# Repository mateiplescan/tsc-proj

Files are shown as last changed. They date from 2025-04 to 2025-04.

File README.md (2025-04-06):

# OpenBook &copy; Matei-Bogdan Plescan 2025

## Diagrama bloc
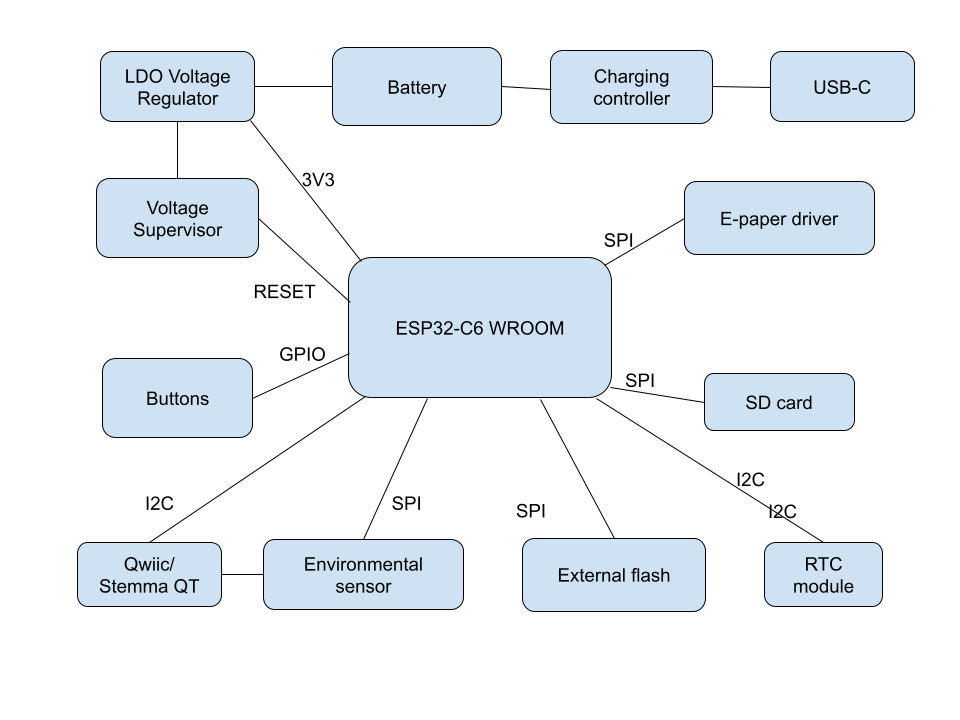
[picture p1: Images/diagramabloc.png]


## Randare 3D
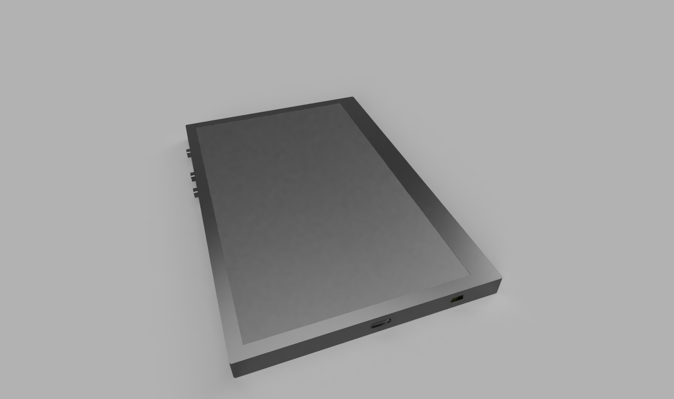
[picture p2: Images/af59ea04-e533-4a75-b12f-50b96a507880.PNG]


## Bill of Materials

| Piesă | Qty | Datasheet | Aprovizionare  |
|---|---|---|---|
| ADAFRUIT_CHIP-LED0603 | 1 | [Link](https://www.snapeda.com/parts/KP-1608SURCK/Kingbright/datasheet/) | [Link](https://www.arrow.com/en/products/kp-1608surck/kingbright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) |
| SJ | 1 | [Link](https://grabcad.com/library/solder-jumpers-1) | [Link](https://grabcad.com/library/solder-jumpers-1) |
| ESP32_WROVER_EAGLE-LTSPICE_R0402 | 24 | [Link](https://ro.mouser.com/ProductDetail/YAGEO/RC0402FR-07100KL?qs=mnq%2FyloZIXzTlUn7JAHSWg%3D%3D) | [Link](https://ro.mouser.com/ProductDetail/YAGEO/RC0402FR-07100KL?qs=mnq%2FyloZIXzTlUn7JAHSWg%3D%3D) |
| ESP32_WROVER_EAGLE-LTSPICE_C0402 | 26 | [Link](https://eu.mouser.com/datasheet/2/447/upy_gphc_x5r_4v_to_50v-3461255.pdf) | [Link](https://eu.mouser.com/ProductDetail/YAGEO/CC0402MRX5R5BB106?qs=zEY9bCHj09eCmUJdZuS5Lg%3D%3D) |
| RCL_CT3528 | 1 | [Link](https://ro.mouser.com/ProductDetail/KEMET/T491B107M006AT?qs=U312oeP%2FpiHOgyk6KO2m0g%3D%3D) | [Link](https://ro.mouser.com/ProductDetail/KEMET/T491B107M006AT?qs=U312oeP%2FpiHOgyk6KO2m0g%3D%3D) |
| 112ATAARR03ATTEND | 1 | [Link](https://store.comet.bg/download-file.php?id=27596) | [Link](https://store.comet.srl.ro/Catalogue/Product/43497/) |
| ESP32_WROVER_SPARKFUN-DISCRETESEMI_SOT23-3 | 2 | [Link](https://www.diodes.com/assets/Datasheets/DMG2305UX.pdf) | [Link](https://eu.mouser.com/ProductDetail/Diodes-Incorporated/DMG2305UX-7?qs=L1DZKBg7t5F%2FNBHrjfxC%252Bg%3D%3D) |
| IND_4828-WE-TPC_WRE | 1 | [Link](https://www.we-online.com/components/products/datasheet/744043680.pdf) | [Link](https://eu.mouser.com/ProductDetail/Wurth-Elektronik/744043680?qs=PGXP4M47uW6VkZq%252BkzjrHA%3D%3D) |
| SOT95P280X125-5N | 1 | [Link](https://fscdn.rohm.com/en/products/databook/datasheet/ic/power/voltage_detector/bd52xxg-e.pdf) | [Link](https://eu.mouser.com/ProductDetail/ROHM-Semiconductor/BD5229G-TR?qs=4kLU8WoGk0vvnhrrYwdszw%3D%3D) |
| MYBUTTON | 2 | [Link](https://www3.panasonic.biz/ac/e_download/control/switch/light-touch/catalog/sw_lt_eng_3529s_side.pdf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) | [Link](https://eu.mouser.com/ProductDetail/Panasonic/EVQ-P7L01P?qs=rJ%252BziJWpyszWhhNszc02jQ%3D%3D) |
| CAPCP3225X100N | 1 | [Link](https://eu.mouser.com/datasheet/2/360/Seiko_Instruments_MicroBattery_E_20230330_2024Jan_-3561061.pdf) | [Link](https://eu.mouser.com/ProductDetail/Seiko-Semiconductors/CPH3225A?qs=3etwrb1wR%252BhUOph6lAO7eg%3D%3D) |
| SOIC127P1032X265-16N | 1 | [Link](https://eu.mouser.com/datasheet/2/609/DS3231-3421123.pdf) | [Link](https://eu.mouser.com/ProductDetail/Analog-Devices-Maxim-Integrated/DS3231SN?qs=1eQvB6Dk1vhUlr8%2FOrV0Fw%3D%3D) |
| XCVR_ESP32-C6-WROOM-1-N8 | 1 | [Link](https://eu.mouser.com/datasheet/2/891/Espressif_ESP32_C6_WROOM_1__Datasheet_V0_1_PRELIMI-3239987.pdf) | [Link](https://eu.mouser.com/ProductDetail/Espressif-Systems/ESP32-C6-WROOM-1-N8?qs=8Wlm6%252BaMh8ST02Gmwp74cw%3D%3D) |
| ESP32C6_VARISTOR_CT/CN1812 | 1 | [Link](https://www.digikey.ro/en/products/detail/abracon-llc/AMCV-1812H-180-T/4245629) | [Link](https://www.digikey.ro/en/products/detail/abracon-llc/AMCV-1812H-180-T/4245629) |
| ESP32_WROVER_AVX---SD0805S020S1R0_AVX_SD0805S020S1R0_0 | 2 | [Link](https://eu.mouser.com/datasheet/2/40/schottky-3165252.pdf) | [Link](https://eu.mouser.com/ProductDetail/KYOCERA-AVX/SD0805S020S1R0?qs=jCA%252BPfw4LHbpkAoSnwrdjw%3D%3D) |
| ESP32_WROVER_BME680_PSON80P300X300X100-8N | 1 | [Link](https://www.bosch-sensortec.com/media/boschsensortec/downloads/datasheets/bst-bme680-ds001.pdf) | [Link](https://store.comet.srl.ro/Catalogue/Product/50164/) |
| ESP32_WROVER_SPARKFUN-IC-POWER_SOT23-5 | 1 | [Link](https://eu.mouser.com/datasheet/2/268/MCP73831_Family_Data_Sheet_DS20001984H-3441711.pdf) | [Link](https://eu.mouser.com/ProductDetail/Microchip-Technology/MCP73831T-4ADI-OT?qs=hH%252BOa0VZEiBTiqxSV9eepQ%3D%3D) |
| FH34SRJ24S05SH99 | 1 | [Link](https://eu.mouser.com/datasheet/2/760/xc6220-3371556.pdf) | [Link](https://eu.mouser.com/ProductDetail/Torex-Semiconductor/XC6220A331MR-G?qs=AsjdqWjXhJ8ZSWznL1J0gg%3D%3D) |
| SON50P200X200X80-9N | 1 | [Link](https://eu.mouser.com/datasheet/2/609/MAX17048_MAX17049-3469099.pdf) | [Link](https://eu.mouser.com/ProductDetail/Analog-Devices-Maxim-Integrated/MAX17048G%2bT10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) |
| SOD3716X135N | 3 | [Link](https://eu.mouser.com/datasheet/2/40/schottky-3165252.pdf) | [Link](https://eu.mouser.com/ProductDetail/KYOCERA-AVX/SD0805S020S1R0?qs=jCA%252BPfw4LHbpkAoSnwrdjw%3D%3D) |
| DIOC1608X36N | 6 | [Link](https://www.littelfuse.com/assetdocs/pulseguard-esd-suppressors-pgb1-datasheet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) | [Link](https://eu.mouser.com/ProductDetail/Littelfuse/PGB1010603MR?qs=gu7KAQ731URLg4GSnNNN7Q%3D%3D) |
| JST04_1MM_RA | 1 | [Link](https://eu.mouser.com/datasheet/2/813/Qwiic_Connector_Datasheet-1223982.pdf) | [Link](https://eu.mouser.com/ProductDetail/SparkFun/PRT-14417?qs=wd5RIQLrsJhgdz%2FpmZ%2F3GQ%3D%3D) |
| SAMACSYS_PARTS_USB4110GFA | 1 | [Link](https://eu.mouser.com/datasheet/2/837/GCT_USB4110_Product_Drawing___20k_cycles-3455479.pdf) | [Link](https://eu.mouser.com/ProductDetail/GCT/USB4110-GF-A?qs=KUoIvG%2F9IlYiZvIXQjyJeA%3D%3D) |
| SOT65P210X110-3N | 1 | [Link](https://www.vishay.com/doc?63399) | [Link](https://eu.mouser.com/ProductDetail/Vishay-Semiconductors/SI1308EDL-T1-GE3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) |
| SOT95P280X145-6N | 1 | [Link](https://eu.mouser.com/datasheet/2/389/usblc6_2sc6y-1852505.pdf) | [Link](https://eu.mouser.com/ProductDetail/STMicroelectronics/USBLC6-2SC6Y?qs=gNDSiZmRJS%2FOgDexvXkdow%3D%3D) |
| SON127P600X800X80-9N | 11 | [Link](https://eu.mouser.com/datasheet/2/949/Winbond_W25Q512JV_Datasheet-3240039.pdf) | [Link](https://eu.mouser.com/ProductDetail/Winbond/W25Q512JVEIQ?qs=l7cgNqFNU1jw6svr3at6tA%3D%3D) |
| SOT95P280X120-5N | 1 | [Link](https://eu.mouser.com/datasheet/2/760/xc6220-3371556.pdf) | [Link](https://eu.mouser.com/ProductDetail/Torex-Semiconductor/XC6220A331MR-G?qs=AsjdqWjXhJ8ZSWznL1J0gg%3D%3D) |

## Descriere Hardware

OpenBook este bazat pe microcontrollerul ESP32-C6. Dispozitivul integrează un display E-Paper, senzori de mediu, stocare de date pe card SD și memorie flash externă, un ceas de timp real (RTC), management avansat al alimentării cu baterie Li-Po și conector de expansiune Qwiic.

### 1. Microcontroller

* **Componentă:** Modul ESP32-C6-WROOM-1-N8 de la Espressif.
* **Procesor:** Nucleu RISC-V single-core pe 32 de biți, până la 160 MHz.
* **Conectivitate:**
    * Wi-Fi 6 (802.11ax)
    * Bluetooth 5 / Bluetooth Low Energy (BLE)
    * Thread/Zigbee (802.15.4)
* **Memorie:** Include SRAM intern și suportă memorie flash externă (utilizată în design).
* **Interfețe:** Dispune de multiple periferice hardware, inclusiv SPI, I2C, SDIO, USB Serial/JTAG, GPIO, ADC, etc., utilizate extensiv în acest design pentru a comunica cu celelalte componente.
* **Rol:** Acționează ca unitate centrală de procesare, controlând toate celelalte module, colectând date de la senzori, gestionând afișajul, stocarea datelor și comunicațiile wireless.

### 2. Managementul Alimentării

* **Intrare Principală:** Conector USB Type-C.
    * Furnizează 5V (VBUS) pentru alimentarea sistemului și încărcarea bateriei.
    * Include circuite de protecție ESD (USBLC6-2SCISY).
* **Încărcare Baterie:**
    * **Componentă:** MCP73831T-2ACI/OT (Li-Po Battery Charging Controller).
    * **Funcționalitate:** Gestionează procesul de încărcare pentru o baterie de la sursa de 5V (USB).
    * **Indicator Status:** Pinul STAT (conectat la ESP32-C6) indică starea procesului de încărcare. Un LED (CHG_LED) oferă indicație vizuală.
* **Baterie:** Conector standard pentru baterie Li-Po.
* **Regulator de Tensiune:**
    * **Componentă:** XC8220A331MR-G (LDO Voltage Regulator).
    * **Funcționalitate:** Primește tensiune fie de la VBUS (USB 5V), fie de la bateria Li-Po (VBAT, ~3.0V-4.2V) și furnizează o tensiune stabilă de **3.3V** pentru alimentarea ESP32-C6 și a majorității perifericelor.
* **Monitorizare Baterie:**
    * **Componentă:** MAX17048G+T10.
    * **Funcționalitate:** Măsoară tensiunea bateriei și estimează starea de încărcare (SoC) și alte informații relevante despre baterie.
    * **Interfață:** Comunică cu ESP32-C6 prin **I2C**.
* **Supervizor Tensiune și Reset:**
    * **Componentă:** BD5229G-TR (Voltage Supervisor).
    * **Funcționalitate:** Monitorizează tensiunea de 3.3V. Dacă tensiunea scade sub un prag prestabilit, generează un semnal de RESET activ-low pe pinul EN al ESP32-C6, asigurând o pornire și funcționare stabilă. Permite și reset manual prin butonul RESET.

### 3. Afișaj (Display)

* **Tip:** E-Paper Display (EPD).
* **Conector:** FH34SR-245-0.5SH_99 (conector FPC cu 24 pini, pas 0.5mm).
* **Circuit Driver:** Include componente discrete (tranzistori MOSFET precum DMG2305UX-7, drivere de poartă precum 5123-11-GE3) necesare pentru a genera tensiunile și semnalele specifice EPD-urilor.
* **Interfață:** Circuitul driver este controlat de ESP32-C6 prin **SPI**.

### 4. Stocare Date

* **Card SD:**
    * **Slot:** Conector standard pentru card microSD.
    * **Interfață:** Conectat la ESP32-C6 folosind interfața **SPI**. Permite stocarea unor volume mari de date (ex: log-uri, fișiere de configurare, imagini).
* **Memorie Flash Externă:**
    * **Componentă:** W25Q512JVEIQ (NOR Flash, 64 Mbit).
    * **Interfață:** Conectată la ESP32-C6 prin **SPI**.
    * **Rol:** Utilizată pentru stocarea firmware-ului principal, a sistemului de fișiere, a configurațiilor sau a datelor critice.

### 5. Senzori și Timp Real

* **Senzor Ambiental:**
    * **Componentă:** BME688 de la Bosch Sensortec.
    * **Funcționalitate:** Măsoară temperatura, umiditatea relativă, presiunea barometrică și compuși organici volatili (VOC), oferind un indice al calității aerului (IAQ).
    * **Interfață:** Comunică cu ESP32-C6 prin **SPI**.
* **Ceas Timp Real (RTC):**
    * **Componentă:** DS3231SN.
    * **Funcționalitate:** Menține data și ora exactă independent de starea de alimentare a ESP32-C6, datorită unei surse de backup (Supercapacitor CPH3225A - C10). Esențial pentru timestamp-uri precise în log-uri.
    * **Interfață:** Comunică cu ESP32-C6 prin **I2C**.

### 6. Interfață Utilizator și Expansiune

* **Butoane:**
    * **RESET:** Buton tactil conectat la intrarea supervizorului de tensiune (și implicit la pinul EN al ESP32-C6) pentru reset manual.
    * **BOOT (IO9):** Buton tactil conectat la GPIO9. Folosit în mod uzual pentru a pune ESP32 în modul bootloader (pentru programare firmware). Poate fi folosit și ca buton de uz general în aplicație.
    * **CHANGE (IO15):** Buton tactil conectat la GPIO15. Destinat utilizării generale în aplicație (ex: schimbare mod afișaj, trigger acțiune).
* **Conector Expansiune:**
    * **Tip:** Conector Qwiic / Stemma QT (standard SparkFun / Adafruit).
    * **Funcționalitate:** Expune magistrala **I2C** a ESP32-C6 (SDA, SCL), împreună cu 3.3V și GND, permițând conectarea ușoară a numeroase module și senzori externi compatibili.

### 7. Alocarea Pinilor ESP32-C6 (Modul U2)

| **Pin** | **Semnal** | **Componentă** | **Rol** |
|---|---|---|---|
| EN | RESET | Buton Reset | Intrare pentru resetarea sistemului |
| IO0 | INT_RTC | RTC DS3231SN | Întrerupere de la RTC pentru evenimente temporale |
| IO1 | 32KHZ | RTC DS3231SN | Semnal de ceas 32kHz de la modulul RTC |
| IO2 | MISO | Magistrala SPI | Intrare de date de la periferice SPI |
| IO3 | EPD_BUSY | Afișaj E-Paper | Monitorizarea stării de disponibilitate a afișajului |
| IO4 | SS_SD | Card SD | Selectare chip pentru cardul SD |
| IO5 | EPD_DC | Afișaj E-Paper | Selectare date/comandă pentru afișaj |
| IO6 | SCK | Magistrala SPI | Semnal de ceas pentru comunicația SPI |
| IO7 | MOSI | Magistrala SPI | Ieșire de date către periferice SPI |
| IO8 | GPIO8 | Uz general | Funcții auxiliare |
| IO9 | IO/BOOT | Buton Boot | Selectare mod boot/programare |
| IO10 | EPD_CS | Afișaj E-Paper | Selectare chip pentru afișajul E-Paper |
| IO11 | FLASH_CS | Flash NOR extern | Selectare chip pentru memoria flash |
| IO12 | USB_D- | Interfață USB  | Linie de date USB negativă |
| IO13 | USB_D+ | Interfață USB  | Linie de date USB pozitivă |
| IO15 | IO/CHANGE | Buton Change | Detectare schimbare de stare |
| IO16/TXD0 | TX | Debug Serial | Transmitere UART |
| IO17/RXD0 | RX | Debug Serial | Recepție UART |
| IO18 | RTC_RST | RTC DS3231SN | Control reset pentru RTC |
| IO19 | I2C_PW | Magistrala I2C | Control alimentare pentru dispozitivele I2C |
| IO20 | EPD_3V3_C | Afișaj E-Paper | Control alimentare pentru afișaj |
| IO21 | SDA | Magistrala I2C | Linie de date I2C |
| IO22 | SCL | Magistrala I2C | Linie de ceas I2C |
| IO23 | EPD_RST | Afișaj E-Paper | Control reset pentru afișaj |

### Justificarea utilizării pinilor ESP32-C6 în DeskAssistant v19:

Alocarea pinilor ESP32-C6 în acest design a fost făcută cu atenție pentru a optimiza funcționalitatea și a gestiona eficient resursele limitate ale microcontrolerului:

- **Grupare funcțională**: Pinii sunt organizați pentru a grupa funcționalitățile similare. De exemplu, pinii pentru interfața SPI (MISO, MOSI, SCK) sunt plasați strategic pentru a facilita rutarea PCB și a reduce interferențele.

- **Pini speciali pentru interfețe standard**: IO21 și IO22 sunt utilizați pentru SDA și SCL, fiind pinii standard recomandați pentru I2C pe ESP32. Similar, IO16 și IO17 sunt utilizați pentru funcțiile UART datorită implementării hardware dedicate.

- **Pini GPIO cu funcționalități speciale pentru afișajul E-Paper**: Afișajul E-Paper necesită control complex, de aceea are alocați mai mulți pini (EPD_BUSY, EPD_DC, EPD_CS, EPD_RST, EPD_3V3_C) pentru funcționarea corectă și eficientă.

- **Management energie**: Pinul IO19 este dedicat controlului alimentării dispozitivelor I2C, permițând economisirea energiei prin oprirea acestora când nu sunt utilizate, esențial pentru un dispozitiv alimentat de baterie.

- **Comunicație cu memoria externă**: Memoria flash NOR necesită acces rapid și fiabil, de aceea utilizează un pin dedicat pentru selecție (IO11) pe lângă liniile standard SPI.

- **Conectivitate USB**: Pinii IO12 și IO13 sunt utilizați pentru USB_D- și USB_D+, permițând conectivitatea directă prin USB fără circuite externe suplimentare.

- **Integrare RTC**: Modulul RTC are multiple conexiuni (INT_RTC, 32KHZ, RTC_RST) pentru o funcționalitate completă, oferind atât ceas precis, cât și capacitatea de a trezi microcontrolerul din starea de somn profund.

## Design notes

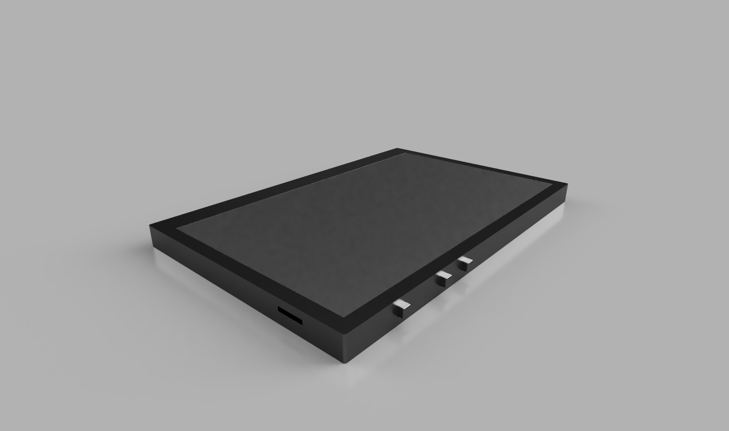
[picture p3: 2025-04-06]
Images/Full_product_2025-Apr-06_02-40-02PM-000_CustomizedView3090269307.png

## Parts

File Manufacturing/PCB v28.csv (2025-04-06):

Qty | Value | Device | Package | Parts | Description | ARROW_PART_NUMBER | ARROW_PRICE-STOCK | AVAILABILITY | CENTROID_NOT_SPECIFIED | CHECK_PRICES | COPYRIGHT | DATASHEET | DESCRIPTION | DIGIKEY_DESCRIPTION | DIGIKEY_PART_NUMBER | HEIGHT | LEAD_FREE | MANUFACTURER_NAME | MANUFACTURER_PART_NUMBER | MF | MFR_NAME | MOUSER_PART_NUMBER | MOUSER_PRICE-STOCK | MOUSER_TESTING_PART_NUMBER | MOUSER_TESTING_PRICE-STOCK | MP | MPN | PACKAGE | POPULARITY | PREFIX | PRICE | PROD_ID | PURCHASE-URL | ROHS | SNAPEDA_LINK | SPICEMODEL | SPICEPREFIX | TEMPERATURE_RANGE_HIGH | TEMPERATURE_RANGE_LOW | TP_SIGNAL_NAME | VALUE
1 |  | ADAFRUIT_LEDCHIP-LED0603 | ADAFRUIT_CHIP-LED0603 | CHG_LED | LED
1 |  | SJ | SJ | SJ1 | SMD solder JUMPER |  |  |  |  |  |  |  |  |  |  |  |  |  |  |  |  |  |  |  |  |  |  |  | 3
1 | 0.47 | ESP32_WROVER_EAGLE-LTSPICE_RR0402 | ESP32_WROVER_EAGLE-LTSPICE_R0402 | R3 | RESISTOR, European symbol |  |  |  |  |  |  |  |  |  |  |  |  |  |  |  |  |  |  |  |  |  |  |  |  |  |  |  |  |  |  | NONE | R
1 | 100k | ESP32_WROVER_EAGLE-LTSPICE_RR0402 | ESP32_WROVER_EAGLE-LTSPICE_R0402 | R1-PWRUSB | RESISTOR, European symbol |  |  |  |  |  |  |  |  |  |  |  |  |  |  |  |  |  |  |  |  |  |  |  |  |  |  |  |  |  |  | NONE | R
7 | 100nF | EAGLE-LTSPICE_CC0402 | EAGLE-LTSPICE_C0402 | C1, C2, C6, C8, C9, C10, C_DELAY | CAPACITOR, European symbol |  |  |  |  |  |  |  |  |  |  |  |  |  |  |  |  |  |  |  |  |  |  |  |  |  |  |  |  |  |  | NONE | C
1 | 100nF | ESP32_WROVER_EAGLE-LTSPICE_CC0402 | ESP32_WROVER_EAGLE-LTSPICE_C0402 | C4-USB | CAPACITOR, European symbol |  |  |  |  |  |  |  |  |  |  |  |  |  |  |  |  |  |  |  |  |  |  |  |  |  |  |  |  |  |  | NONE | C
1 | 100uF TANT | RCL_CPOL-EUCT3528 | RCL_CT3528 | C3 | POLARIZED CAPACITOR, European symbol |  |  |  |  |  |  |  |  |  |  |  |  |  |  |  |  |  |  |  |  |  |  |  | 0 |  |  |  |  |  |  |  | C
16 | 10k | ESP32_WROVER_EAGLE-LTSPICE_RR0402 | ESP32_WROVER_EAGLE-LTSPICE_R0402 | R1, R1_PINH, R1_PINH1, R2_PINH, R2_PINH1, R4, R5, R6, R7, R8, R9, R10, R_BOOT, R_CHANGE, R_CL1, R_RESET | RESISTOR, European symbol |  |  |  |  |  |  |  |  |  |  |  |  |  |  |  |  |  |  |  |  |  |  |  |  |  |  |  |  |  |  | NONE | R
1 | 10uF | EAGLE-LTSPICE_CC0402 | EAGLE-LTSPICE_C0402 | C7 | CAPACITOR, European symbol |  |  |  |  |  |  |  |  |  |  |  |  |  |  |  |  |  |  |  |  |  |  |  |  |  |  |  |  |  |  | NONE | C
1 | 112A-TAAR-R03_ATTEND | 112A-TAAR-R03_ATTEND | 112ATAARR03ATTEND | J4 | Micro SD Card Socket, Push-Push Type, Top Mount, SMT, H=1.83mm, 10u |  |  |  |  |  |  |  | Micro SD Card Socket | Push-Push Type | Top Mount | SMT | H=1.83mm | 10u |  |  | 1.9mm |  | ATTEND | 112A-TAAR-R03 ATTEND
1 | 15 | ESP32_WROVER_EAGLE-LTSPICE_RR0402 | ESP32_WROVER_EAGLE-LTSPICE_R0402 | R_CAPACITOR | RESISTOR, European symbol |  |  |  |  |  |  |  |  |  |  |  |  |  |  |  |  |  |  |  |  |  |  |  |  |  |  |  |  |  |  | NONE | R
1 | 1uF | EAGLE-LTSPICE_CC0402 | EAGLE-LTSPICE_C0402 | C5 | CAPACITOR, European symbol |  |  |  |  |  |  |  |  |  |  |  |  |  |  |  |  |  |  |  |  |  |  |  |  |  |  |  |  |  |  | NONE | C
10 | 1uF/50V | EAGLE-LTSPICE_CC0402 | EAGLE-LTSPICE_C0402 | EPD_C1, EPD_C2, EPD_C5, EPD_C6, EPD_C7, EPD_C8, EPD_C9, EPD_C10, EPD_C11, EPD_C12 | CAPACITOR, European symbol |  |  |  |  |  |  |  |  |  |  |  |  |  |  |  |  |  |  |  |  |  |  |  |  |  |  |  |  |  |  | NONE | C
1 | 2.2 | ESP32_WROVER_EAGLE-LTSPICE_RR0402 | ESP32_WROVER_EAGLE-LTSPICE_R0402 | R2 | RESISTOR, European symbol |  |  |  |  |  |  |  |  |  |  |  |  |  |  |  |  |  |  |  |  |  |  |  |  |  |  |  |  |  |  | NONE | R
1 | 200 | ESP32_WROVER_EAGLE-LTSPICE_RR0402 | ESP32_WROVER_EAGLE-LTSPICE_R0402 | R1_BAT | RESISTOR, European symbol |  |  |  |  |  |  |  |  |  |  |  |  |  |  |  |  |  |  |  |  |  |  |  |  |  |  |  |  |  |  | NONE | R
2 | 20V/4.2A/52mΩ/1.4W | ESP32_WROVER_SPARKFUN-DISCRETESEMI_MOSFET_PCH-DMG2305UX-7 | ESP32_WROVER_SPARKFUN-DISCRETESEMI_SOT23-3 | Q1, Q2 | P-channel MOSFETs |  |  |  |  |  |  |  |  |  |  |  |  |  |  |  |  |  |  |  |  |  |  |  |  |  |  | TRAN-14388 |  |  |  |  |  |  |  |  | 20V/4.2A/52mΩ/1.4W
1 | 2k | ESP32_WROVER_EAGLE-LTSPICE_RR0402 | ESP32_WROVER_EAGLE-LTSPICE_R0402 | R2_BAT | RESISTOR, European symbol |  |  |  |  |  |  |  |  |  |  |  |  |  |  |  |  |  |  |  |  |  |  |  |  |  |  |  |  |  |  | NONE | R
2 | 4.7uF | EAGLE-LTSPICE_CC0402 | EAGLE-LTSPICE_C0402 | C1_BAT, C2_BAT | CAPACITOR, European symbol |  |  |  |  |  |  |  |  |  |  |  |  |  |  |  |  |  |  |  |  |  |  |  |  |  |  |  |  |  |  | NONE | C
3 | 4.7uF | ESP32_WROVER_EAGLE-LTSPICE_CC0402 | ESP32_WROVER_EAGLE-LTSPICE_C0402 | C1_BAT1, C1_BAT2, C5-USB | CAPACITOR, European symbol |  |  |  |  |  |  |  |  |  |  |  |  |  |  |  |  |  |  |  |  |  |  |  |  |  |  |  |  |  |  | NONE | C
1 | 4.7uF/25V | EAGLE-LTSPICE_CC0402 | EAGLE-LTSPICE_C0402 | C4 | CAPACITOR, European symbol |  |  |  |  |  |  |  |  |  |  |  |  |  |  |  |  |  |  |  |  |  |  |  |  |  |  |  |  |  |  | NONE | C
2 | 5k1 | ESP32_WROVER_EAGLE-LTSPICE_RR0402 | ESP32_WROVER_EAGLE-LTSPICE_R0402 | R2-USB, R2-USB1 | RESISTOR, European symbol |  |  |  |  |  |  |  |  |  |  |  |  |  |  |  |  |  |  |  |  |  |  |  |  |  |  |  |  |  |  | NONE | R
1 | 68uH | 744043680IND_4828-WE-TPC_WRE | IND_4828-WE-TPC_WRE | L1 |  |  |  |  |  |  | Copyright (C) 2024 Ultra Librarian. All rights reserved. |  |  |  |  |  |  |  | 744043680 |  | Wurth Electronics
1 | BD5229G-TR | BD5229G-TR | SOT95P280X125-5N | IC1 | Voltage Detector with Adjustable Delay Time: CMOS processes are utilized to develop high precision, low current consumption CMOS reset ICs that allow arbitrary setting of the delay time. The extensive lineup includes both Nch Open Drain and CMOS output types in a wide range of detection voltages (from 2.3V to 6.0V, in 0.1V steps), enabling selection of the ideal solution based on customer requirements. In addition, the entire series is of course both lead-free and RoHS-compliant. |  |  |  |  |  |  |  | Voltage Detector with Adjustable Delay Time: CMOS processes are utilized to develop high precision | low current consumption CMOS reset ICs that allow arbitrary setting of the delay time. The extensive lineup includes both Nch Open Drain and CMOS output types in a wide range of detection voltages (from 2.3V to 6.0V | in 0.1V steps) | enabling selection of the ideal solution based on customer requirements. In addition | the entire series is of course both lead-free and RoHS-compliant. |  |  | 1.25mm |  | ROHM Semiconductor | BD5229G-TR |  |  | 755-BD5229G-TR | https://www.mouser.co.uk/ProductDetail/ROHM-Semiconductor/BD5229G-TR?qs=4kLU8WoGk0vvnhrrYwdszw%3D%3D
3 | BUTTON_CUSYOMV1 | BUTTON_CUSYOMV1 | MYBUTTON | BOOT_BUTTON, CHANGE_BUTTON, RESET_BUTTON
1 | CPH3225A | CPH3225A | CAPCP3225X100N | C10_SUPERCAP | Cap 0.011F 3.3V 1210 Flat Check availability |  |  | Not in stock |  | https://www.snapeda.com/parts/CPH3225A/Seiko+Instruments/view-part/?ref=eda |  |  | 11 mF (EDLC) Supercapacitor 3.3 V 1210 (3225 Metric) - - |  |  |  |  |  |  | Seiko Instruments |  |  |  |  |  | CPH3225A |  | 1210 Seiko |  |  | None |  | https://www.snapeda.com/api/url_track_click_mouser/?unipart_id=562593&manufacturer=Seiko Instruments&part_name=CPH3225A&search_term=None |  | https://www.snapeda.com/parts/CPH3225A/Seiko+Instruments/view-part/?ref=snap
1 | DS3231SN# | DS3231SN# | SOIC127P1032X265-16N | U3 | Real Time Clock Serial 16-Pin SOIC W T/R Check availability |  |  | In Stock |  | https://www.snapeda.com/parts/DS3231SN%23/Analog+Devices/view-part/?ref=eda |  |  | Extremely Accurate I²C-Integrated RTC/TCXO/Crystal |  |  |  |  |  |  | Analog Devices |  |  |  |  |  | DS3231SN# |  | SOIC-16 Maxim |  |  | None |  | https://www.snapeda.com/api/url_track_click_mouser/?unipart_id=99048&manufacturer=Analog Devices&part_name=DS3231SN#&search_term=None |  | https://www.snapeda.com/parts/DS3231SN%23/Analog+Devices/view-part/?ref=snap
1 | ESP32-C6-WROOM-1-N8 | ESP32-C6-WROOM-1-N8 | XCVR_ESP32-C6-WROOM-1-N8 | U2 | Check availability |  |  | In Stock |  | https://www.snapeda.com/parts/ESP32-C6-WROOM-1-N8/Espressif+Systems/view-part/?ref=eda |  |  | Multiprotocol Modules ESP32-C6 module | Wi-Fi 6 in 2.4 GHz band | Bluetooth 5 | Zigbee 3.0 and Thread. ESP34-WROOM Compatible - ENGINEERING SAMPLE |  |  |  |  |  |  | Espressif Systems |  |  |  |  |  | ESP32-C6-WROOM-1-N8 |  | None |  |  | None |  |  |  | https://www.snapeda.com/parts/ESP32-C6-WROOM-1-N8/Espressif+Systems/view-part/?ref=snap
1 | ESP32C6_VARISTORCN1812 | ESP32C6_VARISTORCN1812 | ESP32C6_VARISTOR_CT/CN1812 | PFMF.050.1 | VARISTOR |  |  |  |  |  |  |  |  |  |  |  |  |  |  |  |  |  |  |  |  |  |  |  | 0
2 | ESP32_WROVER_AVX---SD0805S020S1R0_AVX_SD0805S020S1R0_0_0AVX_SD0805S020S1R0_0_0 | ESP32_WROVER_AVX---SD0805S020S1R0_AVX_SD0805S020S1R0_0_0AVX_SD0805S020S1R0_0_0 | ESP32_WROVER_AVX---SD0805S020S1R0_AVX_SD0805S020S1R0_0 | D2, D7 | Schottky Barrier Rectifier Diode |  |  |  | No |  |  | http://datasheets.avx.com/schottky.pdf |  | DIODE SCHOTTKY 20V 1A 0805 | 478-7800-1-ND |  | yes |  |  | AVX |  | 581-SD0805S020S1R0 |  |  |  |  |  | 0805 (2012 metric) |  | D |  |  |  | yes |  |  |  | +125°C | -55°C
1 | ESP32_WROVER_BME680_BME680 | ESP32_WROVER_BME680_BME680 | ESP32_WROVER_BME680_PSON80P300X300X100-8N | SENSOR2 | Integrated Environmental Unit |  |  | Unavailable |  |  |  |  | Integrated Environmental Unit |  |  |  |  |  |  | Bosch Sensortec |  |  |  |  |  | BME680 |  | LGA-8 Bosch Tools |  |  | None
1 | ESP32_WROVER_SPARKFUN-IC-POWER_MCP73831 | ESP32_WROVER_SPARKFUN-IC-POWER_MCP73831 | ESP32_WROVER_SPARKFUN-IC-POWER_SOT23-5 | MCP73831 | MCP73831T Li-Ion, Li-Pol Controller |  |  |  |  |  |  |  |  |  |  |  |  |  |  |  |  |  |  |  |  |  |  |  |  |  |  | IC-09995
1 | FH34SRJ-24S-0.5SH_99_ | FH34SRJ-24S-0.5SH_99_ | FH34SRJ24S05SH99 | J1 | (0.50mm) Surface Mount, Right Angle |  |  |  |  |  |  |  | 24 Position FFC | FPC Connector Contacts | (0.50mm) Surface Mount | Right Angle |  |  | 1.1mm |  | Hirose | FH34SRJ-24S-0.5SH(99) |  |  | 798-FH34SRJ24S05SH99 | https://www.mouser.co.uk/ProductDetail/Hirose-Connector/FH34SRJ-24S-0.5SH99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
1 | MAX17048G+T10 | MAX17048G+T10 | SON50P200X200X80-9N | U4 | Check availability |  |  | In Stock |  | https://www.snapeda.com/parts/MAX17048G+T10/Analog+Devices/view-part/?ref=eda |  |  | 3µA 1-Cell/2-Cell Fuel Gauge with ModelGauge |  |  |  |  |  |  | Analog Devices |  |  |  |  |  | MAX17048G+T10 |  | TDFN-8 Maxim |  |  | None |  | https://www.snapeda.com/api/url_track_click_mouser/?unipart_id=329239&manufacturer=Analog Devices&part_name=MAX17048G+T10&search_term=None |  | https://www.snapeda.com/parts/MAX17048G+T10/Analog+Devices/view-part/?ref=snap
3 | MBR0530 | MBR0530 | SOD3716X135N | D3, D4, D5 | ON SEMICONDUCTOR - MBR0530 - DIODE, SCHOTTKY, 0.5A, 30V, SOD-123 |  |  | In Stock |  | https://www.snapeda.com/parts/MBR0530/Onsemi/view-part/?ref=eda |  |  | Diode Schottky 30 V 500mA Surface Mount SOD-123 |  |  |  |  |  |  | ON Semiconductor |  |  |  |  |  | MBR0530 |  | SOD-123-2 ON Semiconductor |  |  | None |  | https://www.snapeda.com/api/url_track_click_mouser/?unipart_id=179458&manufacturer=ON Semiconductor&part_name=MBR0530&search_term=None |  | https://www.snapeda.com/parts/MBR0530/Onsemi/view-part/?ref=snap
6 | PGB1010603MR | PGB1010603MR | DIOC1608X36N | D6, D8, D9, D10, D11, D12 | Check availability |  |  | In Stock |  | https://www.snapeda.com/parts/PGB1010603MR/Littelfuse/view-part/?ref=eda |  |  | 150V (Typ) Clamp - Ipp Tvs Diode Surface Mount 0603 (1608 Metric) |  |  |  |  |  |  | Littelfuse Inc. |  |  |  |  |  | PGB1010603MR |  | 0603 Littelfuse Inc. |  |  | None |  | https://www.snapeda.com/api/url_track_click_mouser/?unipart_id=5659453&manufacturer=Littelfuse Inc.&part_name=PGB1010603MR&search_term=None |  | https://www.snapeda.com/parts/PGB1010603MR/Littelfuse/view-part/?ref=snap
1 | QWIIC_RIGHT_ANGLE | QWIIC_CONNECTORJS-1MM | JST04_1MM_RA | J3 | SparkFun I2C Standard Qwiic Connector |  |  |  |  |  |  |  |  |  |  |  |  |  |  |  |  |  |  |  |  |  |  |  |  |  |  | CONN-13694 |  |  |  |  |  |  |  |  | QWIIC_RIGHT_ANGLE
1 | SAMACSYS_PARTS_USB4110-GF-A | SAMACSYS_PARTS_USB4110-GF-A | SAMACSYS_PARTS_USB4110GFA | J2 | CONN USB 2.0 TYPE-C R/A SMT |  |  |  |  |  |  |  | CONN USB 2.0 TYPE-C R/A SMT |  |  | 3.26mm |  | GCT (GLOBAL CONNECTOR TECHNOLOGY) | USB4110-GF-A |  |  | 640-USB4110-GF-A | https://www.mouser.co.uk/ProductDetail/GCT/USB4110-GF-A?qs=KUoIvG%2F9IlYiZvIXQjyJeA%3D%3D
1 | SI1308EDL-T1-GE3 | SI1308EDL-T1-GE3 | SOT65P210X110-3N | Q3 | MOSFET N-Ch 30V 1.5A TrenchFET SC70 Vishay Si1308EDL-T1-GE3 N-channel MOSFET Transistor, 1.5 A, 30 V, 3-Pin SC-70 |  |  | In Stock |  | https://www.snapeda.com/parts/SI1308EDL-T1-GE3/Vishay+Siliconix/view-part/?ref=eda |  |  | Si1308EDL-T1-GE3 N-channel MOSFET Transistor | 1.5 A | 30 V | 3-Pin SC-70 | Siliconix / Vishay SI1308EDL-T1-GE3 |  |  |  |  |  |  | Vishay Siliconix |  |  |  |  |  | SI1308EDL-T1-GE3 |  | SOT-323 Vishay Semiconductor |  |  | None |  | https://www.snapeda.com/api/url_track_click_mouser/?unipart_id=274603&manufacturer=Vishay Siliconix&part_name=SI1308EDL-T1-GE3&search_term=None |  | https://www.snapeda.com/parts/SI1308EDL-T1-GE3/Vishay+Siliconix/view-part/?ref=snap
17 | TPTP20R | TPTP20R | TP20R | TP1, TP2, TP3, TP4, TP5, TP6, TP7, TP8, TP9, TP10, TP11, TP12, TP13, TP14, TP15, TP16, TP17 | Test pad |  |  |  |  |  |  |  |  |  |  |  |  |  |  |  |  |  |  |  |  |  |  |  | 2
1 | USBLC6-2SC6Y | USBLC6-2SC6Y | SOT95P280X145-6N | D1 | Low Cap. ESD Protection Auto SOT-23-6 STMicroelectronics USBLC6-2SC6Y, Dual Uni-Directional TVS Diode Array, 6-Pin SOT-23 |  |  | In Stock |  | https://www.snapeda.com/parts/USBLC6-2SC6Y/STMicroelectronics/view-part/?ref=eda |  |  | 17V Clamp 5A (8/20µs) Ipp Tvs Diode Surface Mount SOT-23-6 |  |  |  |  |  |  | STMicroelectronics |  |  |  |  |  | USBLC6-2SC6Y |  | SOT-23-6 STMicroelectronics |  |  | None |  |  |  | https://www.snapeda.com/parts/USBLC6-2SC6Y/STMicroelectronics/view-part/?ref=snap
1 | W25Q512JVEIQ | W25Q512JVEIQ | SON127P600X800X80-9N | U1 | Check availability |  |  | In Stock |  | https://www.snapeda.com/parts/W25Q512JVEIQ/Winbond+Electronics/view-part/?ref=eda |  |  | FLASH - NOR Memory IC 512Mb (64M x 8) SPI - Quad I/O 133 MHz 8-WSON (8x6) |  |  |  |  |  |  | Winbond Electronics |  |  |  |  |  | W25Q512JVEIQ |  | Package |  |  | None |  |  |  | https://www.snapeda.com/parts/W25Q512JVEIQ/Winbond+Electronics/view-part/?ref=snap
1 | XC6220A331MR-G | XC6220A331MR-G | SOT95P280X120-5N | IC4 | LDO Voltage Regulators |  |  |  |  |  |  |  | LDO Voltage Regulators |  |  | 1.2mm |  | Torex | XC6220A331MR-G |  |  | 865-XC6220A331MR-G | https://www.mouser.co.uk/ProductDetail/Torex-Semiconductor/XC6220A331MR-G?qs=AsjdqWjXhJ8ZSWznL1J0gg%3D%3D

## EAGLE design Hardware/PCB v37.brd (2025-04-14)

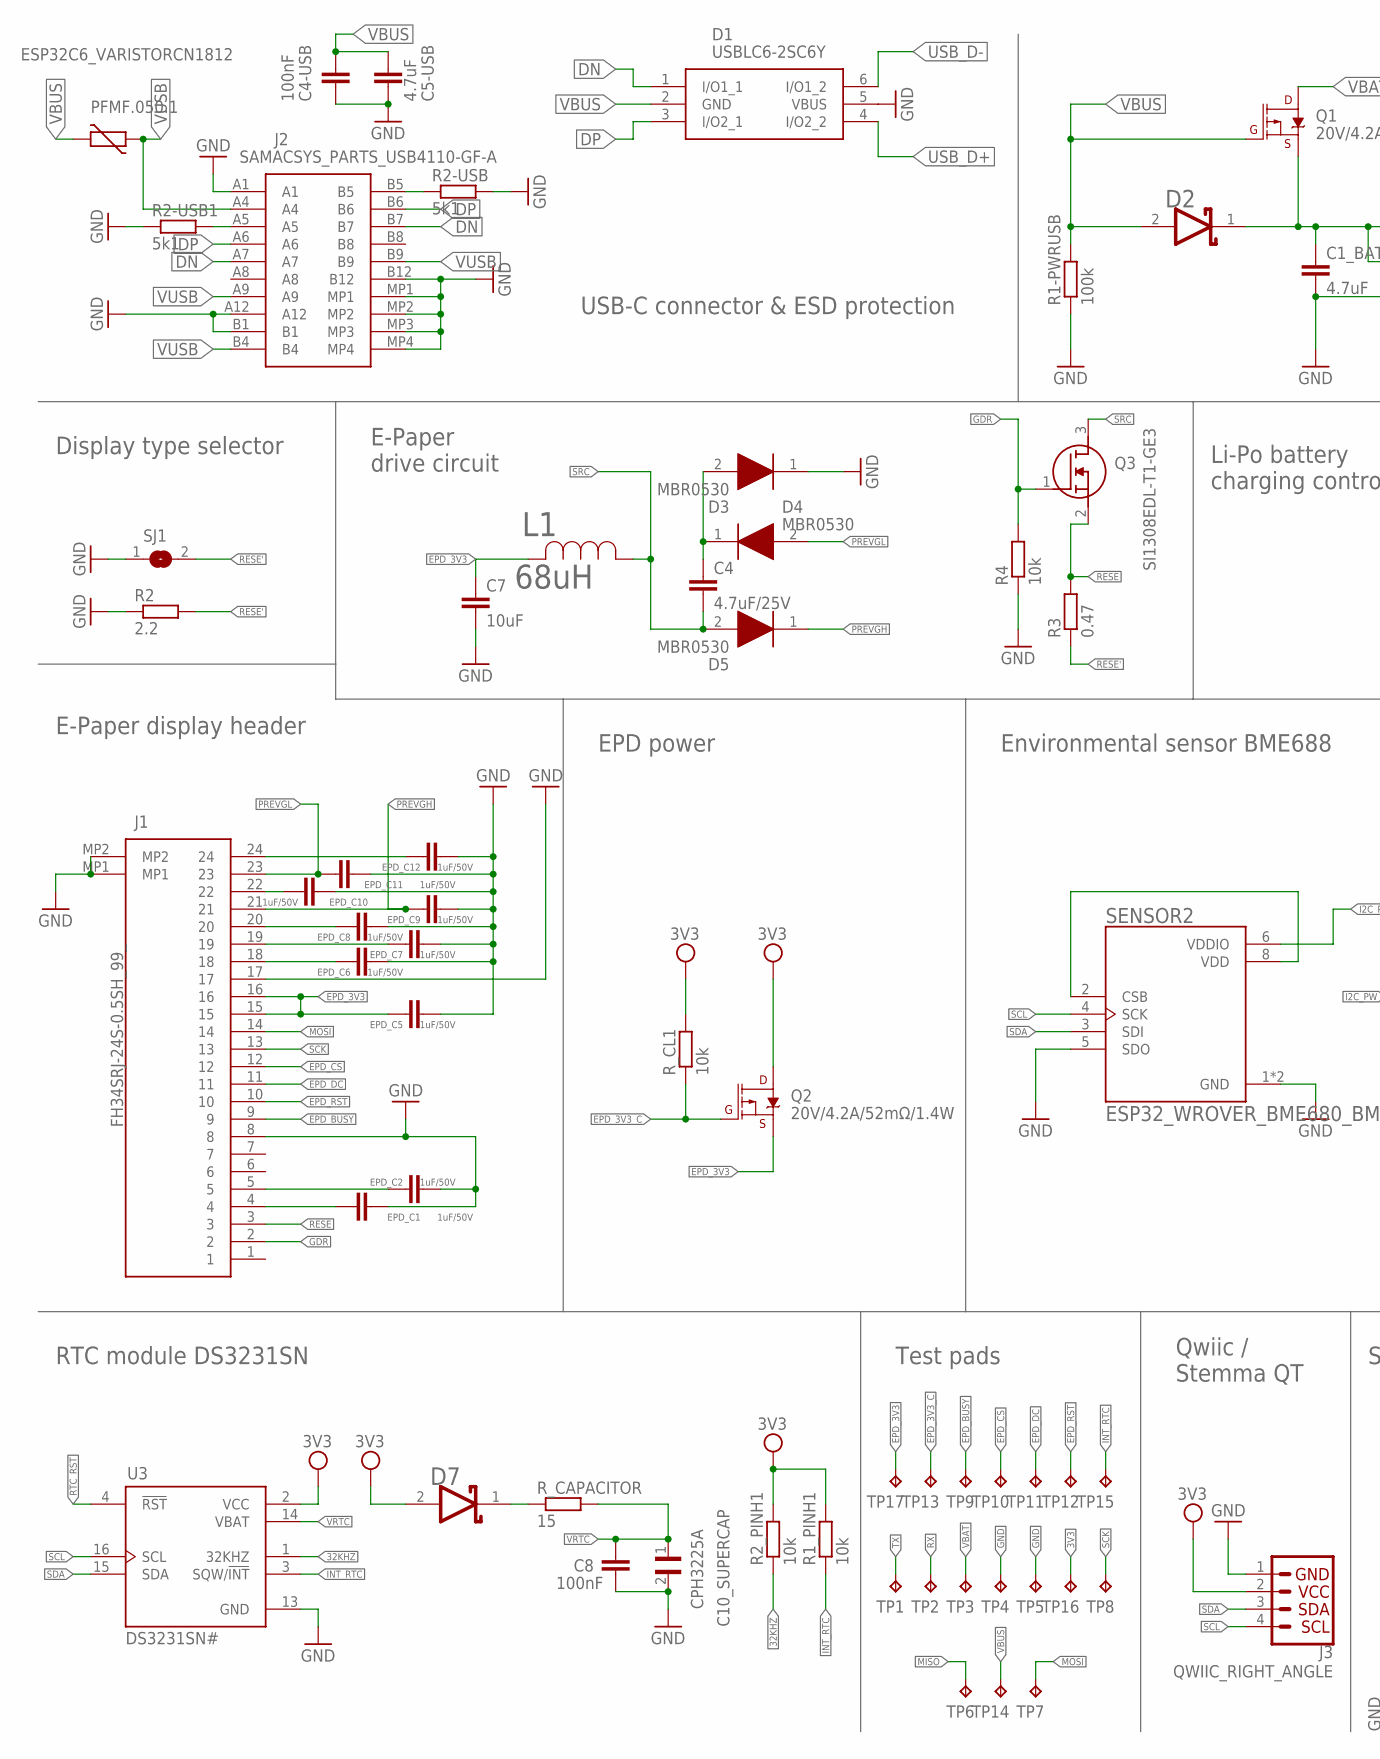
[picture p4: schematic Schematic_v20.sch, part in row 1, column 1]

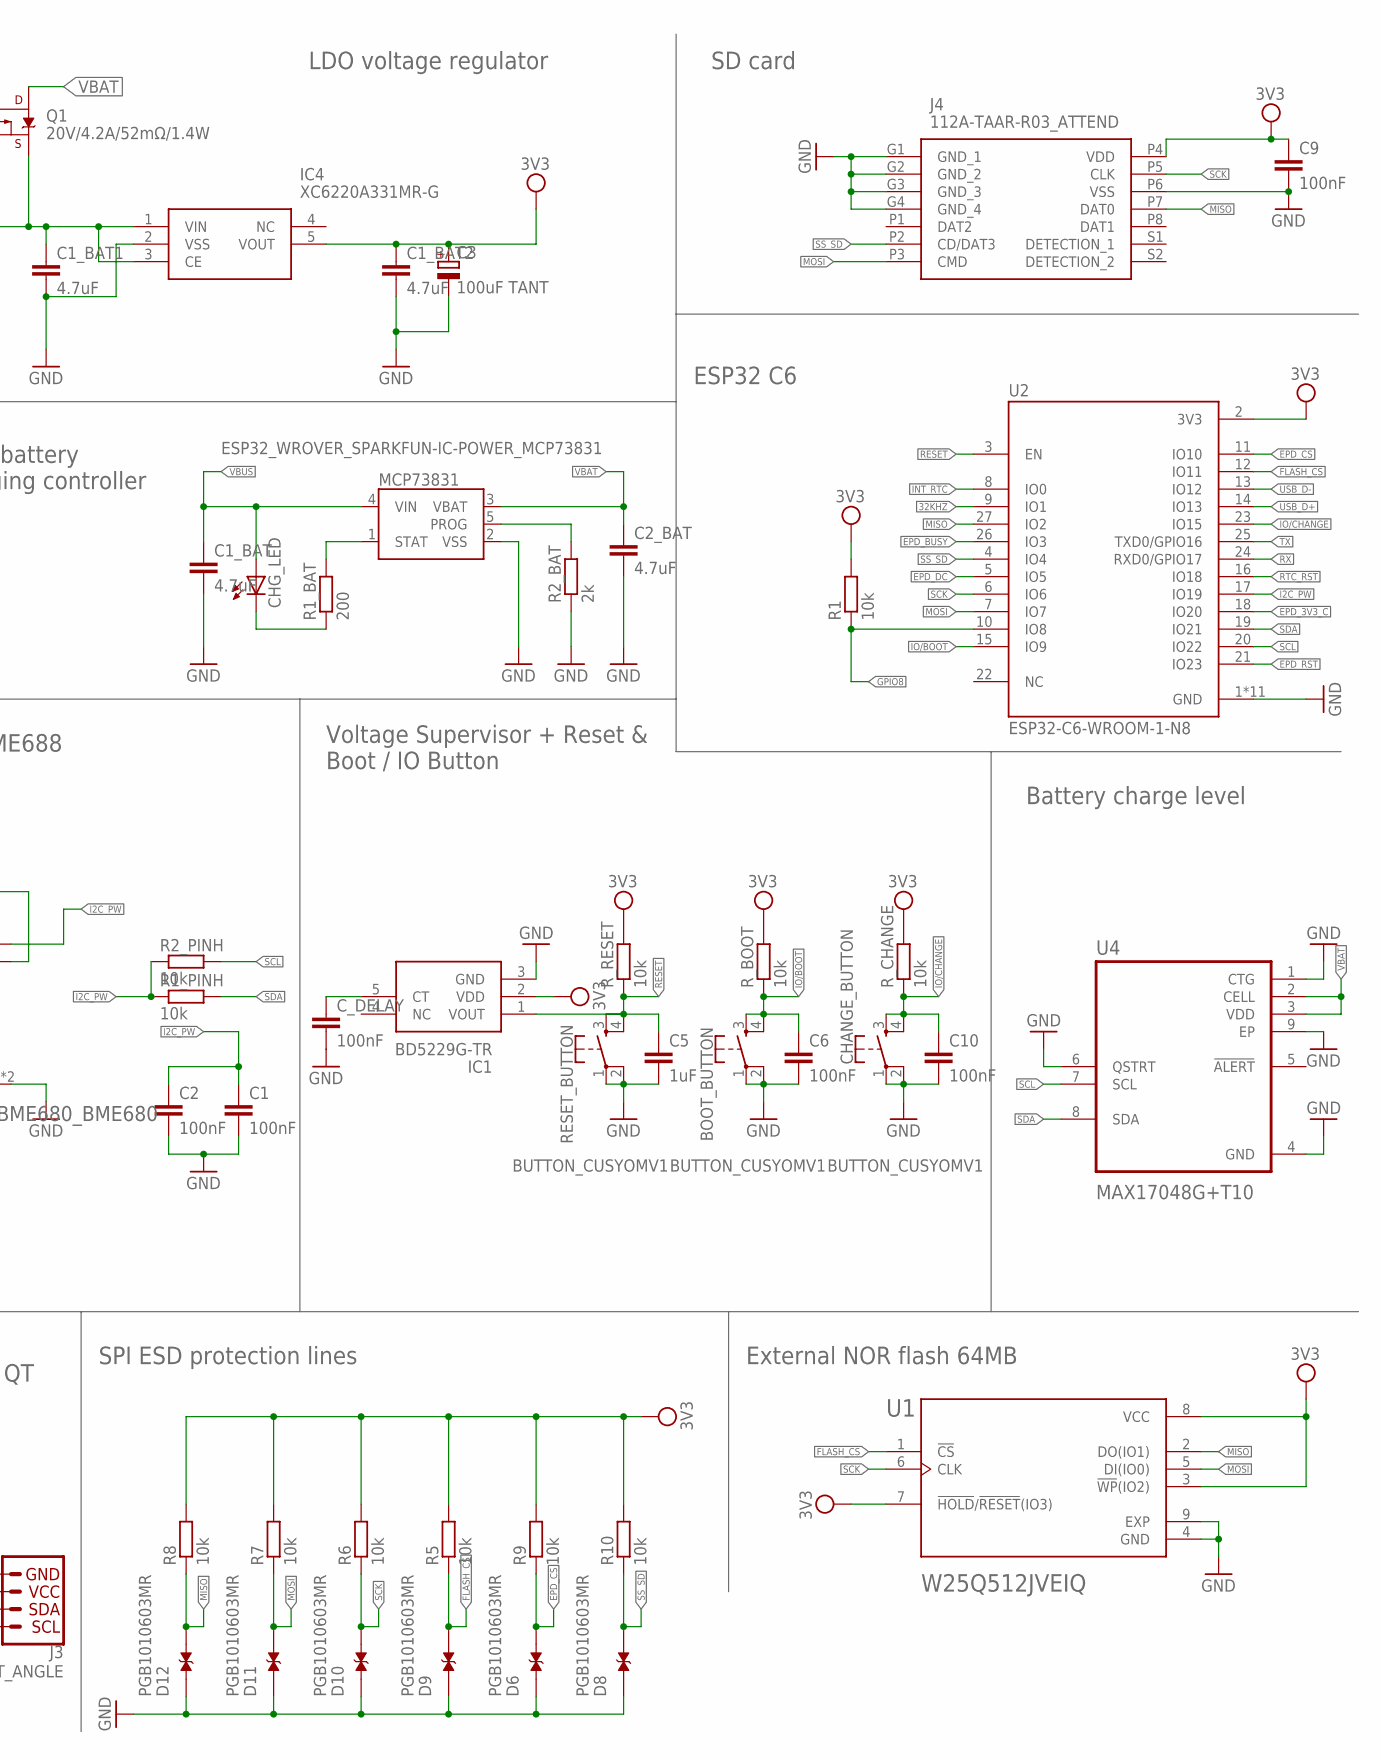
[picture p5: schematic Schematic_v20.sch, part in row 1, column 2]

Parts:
BOOT_BUTTON: BUTTON_CUSYOMV1; MYBUTTON
C1, C2, C6, C8, C9, C10: 100nF; EAGLE-LTSPICE_C0402
C1_BAT, C2_BAT: 4.7uF; EAGLE-LTSPICE_C0402
C1_BAT1, C1_BAT2, C5-USB: 4.7uF; ESP32_WROVER_EAGLE-LTSPICE_C0402
C3: 100uF TANT; RCL_CT3528
C4: 4.7uF/25V; EAGLE-LTSPICE_C0402
C4-USB: 100nF; ESP32_WROVER_EAGLE-LTSPICE_C0402
C5: 1uF; EAGLE-LTSPICE_C0402
C7: 10uF; EAGLE-LTSPICE_C0402
C10_SUPERCAP: CPH3225A; CAPCP3225X100N
CHANGE_BUTTON: BUTTON_CUSYOMV1; MYBUTTON
CHG_LED: ADAFRUIT_LEDCHIP-LED0603; ADAFRUIT_CHIP-LED0603
C_DELAY: 100nF; EAGLE-LTSPICE_C0402
D1: USBLC6-2SC6Y; SOT95P280X145-6N
D2, D7: ESP32_WROVER_AVX---SD0805S020S1R0_AVX_SD0805S020S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; ESP32_WROVER_AVX---SD0805S020S1R0_AVX_SD0805S020S1R0_0
D3, D4, D5: MBR0530; SOD3716X135N
D6, D8, D9, D10, D11, D12: PGB1010603MR; DIOC1608X36N
EPD_C1, EPD_C2, EPD_C5, EPD_C6, EPD_C7, EPD_C8, EPD_C9, EPD_C10, EPD_C11, EPD_C12: 1uF/50V; EAGLE-LTSPICE_C0402
IC1: BD5229G-TR; SOT95P280X125-5N
IC4: XC6220A331MR-G; SOT95P280X120-5N
J1: FH34SRJ-24S-0.5SH_99_; FH34SRJ24S05SH99
J2: SAMACSYS_PARTS_USB4110-GF-A; SAMACSYS_PARTS_USB4110GFA
J3: QWIIC_RIGHT_ANGLE; JST04_1MM_RA
J4: 112A-TAAR-R03_ATTEND; 112ATAARR03ATTEND
L1: 68uH; IND_4828-WE-TPC_WRE
MCP73831: ESP32_WROVER_SPARKFUN-IC-POWER_MCP73831; ESP32_WROVER_SPARKFUN-IC-POWER_SOT23-5
PFMF.050.1: ESP32C6_VARISTORCN1812; ESP32C6_VARISTOR_CT/CN1812
Q1, Q2: 20V/4.2A/52mΩ/1.4W; ESP32_WROVER_SPARKFUN-DISCRETESEMI_SOT23-3
Q3: SI1308EDL-T1-GE3; SOT65P210X110-3N
R1, R1_PINH, R1_PINH1, R2_PINH, R2_PINH1, R4, R5, R6, R7, R8, R9, R10: 10k; ESP32_WROVER_EAGLE-LTSPICE_R0402
R1-PWRUSB: 100k; ESP32_WROVER_EAGLE-LTSPICE_R0402
R1_BAT: 200; ESP32_WROVER_EAGLE-LTSPICE_R0402
R2: 2.2; ESP32_WROVER_EAGLE-LTSPICE_R0402
R2-USB, R2-USB1: 5k1; ESP32_WROVER_EAGLE-LTSPICE_R0402
R2_BAT: 2k; ESP32_WROVER_EAGLE-LTSPICE_R0402
R3: 0.47; ESP32_WROVER_EAGLE-LTSPICE_R0402
RESET_BUTTON: BUTTON_CUSYOMV1; MYBUTTON
R_BOOT: 10k; ESP32_WROVER_EAGLE-LTSPICE_R0402
R_CAPACITOR: 15; ESP32_WROVER_EAGLE-LTSPICE_R0402
R_CHANGE: 10k; ESP32_WROVER_EAGLE-LTSPICE_R0402
R_CL1: 10k; ESP32_WROVER_EAGLE-LTSPICE_R0402
R_RESET: 10k; ESP32_WROVER_EAGLE-LTSPICE_R0402
SENSOR2: ESP32_WROVER_BME680_BME680; ESP32_WROVER_BME680_PSON80P300X300X100-8N
SJ1: SJ
TP1, TP2, TP3, TP4, TP5, TP6, TP7, TP8, TP9, TP10, TP11, TP12, TP13, TP14, TP15, TP16, TP17: TPTP20R; TP20R
U1: W25Q512JVEIQ; SON127P600X800X80-9N
U2: ESP32-C6-WROOM-1-N8; XCVR_ESP32-C6-WROOM-1-N8
U3: DS3231SN#; SOIC127P1032X265-16N
U4: MAX17048G+T10; SON50P200X200X80-9N

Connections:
3V3: C1_BAT2.1, C3.+, C9.1, D7.2 (ANODE), IC1.2 (VDD), IC4.5 (VOUT), J3.2, J4.P4 (VDD), Q2.3 (D), R1.2, R1_PINH1.2, R2_PINH1.2, R5.2, R6.2, R7.2, R8.2, R9.2, R10.2, R_BOOT.2, R_CHANGE.2, R_CL1.2, R_RESET.2, TP16.TP, U1.3 (!WP!(IO2)), U1.7 (!HOLD!/!RESET!(IO3)), U1.8 (VCC), U2.2 (3V3), U3.2 (VCC)
32KHZ: R2_PINH1.1, U2.9 (IO1), U3.1 (32KHZ)
DN: D1.1 (I/O1_1), J2.A7, J2.B7
DP: D1.3 (I/O2_1), J2.A6, J2.B6
EPD_3V3: C7.1, EPD_C5.1, J1.15, J1.16, L1.2, Q2.2 (S), TP17.TP
EPD_3V3_C: Q2.1 (G), R_CL1.1, TP13.TP, U2.18 (IO20)
EPD_BUSY: J1.9, TP9.TP, U2.26 (IO3)
EPD_CS: D6.2, J1.12, R9.1, TP10.TP, U2.11 (IO10)
EPD_DC: J1.11, TP11.TP, U2.5 (IO5)
EPD_RST: J1.10, TP12.TP, U2.21 (IO23)
FLASH_CS: D9.2, R5.1, U1.1 (!CS), U2.12 (IO11)
GDR: J1.2, Q3.1 (G), R4.2
GND: BOOT_BUTTON.1, BOOT_BUTTON.2, C1.2, C1_BAT.2, C1_BAT1.2, C1_BAT2.2, C2.2, C2_BAT.2, C3.-, C4-USB.2, C5.2, C5-USB.2, C6.2, C7.2, C8.2, C9.2, C10.2, C10_SUPERCAP.2, CHANGE_BUTTON.1, CHANGE_BUTTON.2, C_DELAY.2, D1.5 (VBUS), D3.1 (K), D6.1, D8.1, D9.1, D10.1, D11.1, D12.1, EPD_C1.2, EPD_C2.2, EPD_C5.2, EPD_C6.2, EPD_C7.2, EPD_C8.2, EPD_C9.2, EPD_C10.2, EPD_C11.2, EPD_C12.2, IC1.3 (GND), IC4.2 (VSS), J1.8, J1.17, J1.MP1, J1.MP2, J2.A1, J2.A12, J2.B1, J2.B12, J2.MP1, J2.MP2, J2.MP3, J2.MP4, J3.1, J4.G1 (GND_1), J4.G2 (GND_2), J4.G3 (GND_3), J4.G4 (GND_4), J4.P6 (VSS), MCP73831.2 (VSS), R1-PWRUSB.1, R2.1, R2-USB.2, R2-USB1.1, R2_BAT.1, R4.1, RESET_BUTTON.1, RESET_BUTTON.2, SENSOR2.1 (GND), SENSOR2.5 (SDO), SENSOR2.7 (GND), SJ1.1, TP4.TP, TP5.TP, U1.4 (GND), U1.9 (EXP), U2.1 (GND), U2.28 (GND), U2.29_1 (GND), U2.29_2 (GND), U2.29_3 (GND), U2.29_4 (GND), U2.29_5 (GND), U2.29_6 (GND), U2.29_7 (GND), U2.29_8 (GND), U2.29_9 (GND), U3.13 (GND), U4.1 (CTG), U4.4 (GND), U4.6 (QSTRT), U4.9 (EP)
GPIO8: R1.1, U2.10 (IO8)
I2C_PW: C1.1, C2.1, R1_PINH.1, R2_PINH.1, SENSOR2.6 (VDDIO), U2.17 (IO19)
INT_RTC: R1_PINH1.1, TP15.TP, U2.8 (IO0), U3.3 (SQW/!INT)
IO/BOOT: BOOT_BUTTON.3, BOOT_BUTTON.4, C6.1, R_BOOT.1, U2.15 (IO9)
IO/CHANGE: C10.1, CHANGE_BUTTON.3, CHANGE_BUTTON.4, R_CHANGE.1, U2.23 (IO15)
MISO: D12.2, J4.P7 (DAT0), R8.1, TP6.TP, U1.2 (DO(IO1)), U2.27 (IO2)
MOSI: D11.2, J1.14, J4.P3 (CMD), R7.1, TP7.TP, U1.5 (DI(IO0)), U2.7 (IO7)
unnamed: J2.A5, R2-USB1.2
unnamed: J2.B5, R2-USB.1
unnamed: SENSOR2.2 (CSB), SENSOR2.8 (VDD)
unnamed: EPD_C6.1, J1.18
unnamed: C1_BAT1.1, D2.1 (CATHODE), IC4.1 (VIN), IC4.3 (CE), Q1.2 (S)
unnamed: EPD_C7.1, J1.19
unnamed: EPD_C8.1, J1.20
unnamed: C4.1, D3.2 (A), D4.1 (K)
unnamed: EPD_C10.1, J1.22
unnamed: EPD_C12.1, J1.24
unnamed: C_DELAY.1, IC1.5 (CT)
unnamed: MCP73831.1 (STAT), R1_BAT.2
unnamed: CHG_LED.C, R1_BAT.1
unnamed: MCP73831.5 (PROG), R2_BAT.2
unnamed: D7.1 (CATHODE), R_CAPACITOR.1
unnamed: EPD_C1.1, J1.4
unnamed: EPD_C2.1, J1.5
PREVGH: D5.1 (K), EPD_C9.1, J1.21
PREVGL: D4.2 (A), EPD_C11.1, J1.23
RESE: J1.3, Q3.2 (S), R3.2
RESE': R2.2, R3.1, SJ1.2
RESET: C5.1, IC1.1 (VOUT), RESET_BUTTON.3, RESET_BUTTON.4, R_RESET.1, U2.3 (EN)
RTC_RST: U2.16 (IO18), U3.4 (!RST)
RX: TP2.TP, U2.24 (RXD0/GPIO17)
SCK: D10.2, J1.13, J4.P5 (CLK), R6.1, TP8.TP, U1.6 (CLK), U2.6 (IO6)
SCL: J3.4, R2_PINH.2, SENSOR2.4 (SCK), U2.20 (IO22), U3.16 (SCL), U4.7 (SCL)
SDA: J3.3, R1_PINH.2, SENSOR2.3 (SDI), U2.19 (IO21), U3.15 (SDA), U4.8 (SDA)
SRC: C4.2, D5.2 (A), L1.1, Q3.3 (D)
SS_SD: D8.2, J4.P2 (CD/DAT3), R10.1, U2.4 (IO4)
TX: TP1.TP, U2.25 (TXD0/GPIO16)
USB_D+: D1.4 (I/O2_2), U2.14 (IO13)
USB_D-: D1.6 (I/O1_2), U2.13 (IO12)
VBAT: C2_BAT.1, MCP73831.3 (VBAT), Q1.3 (D), TP3.TP, U4.2 (CELL), U4.3 (VDD)
VBUS: C1_BAT.1, C4-USB.1, C5-USB.1, CHG_LED.A, D1.2 (GND), D2.2 (ANODE), MCP73831.4 (VIN), PFMF.050.1.2, Q1.1 (G), R1-PWRUSB.2, TP14.TP
VRTC: C8.1, C10_SUPERCAP.1, R_CAPACITOR.2, U3.14 (VBAT)
VUSB: J2.A4, J2.A9, J2.B4, J2.B9, PFMF.050.1.1

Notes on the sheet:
USB-C connector & ESD protection
LDO voltage regulator
SD card
ESP32 C6
Li-Po battery charging controller
E-Paper drive circuit
Display type selector
E-Paper display header
EPD power
Environmental sensor BME688
Voltage Supervisor + Reset & Boot / IO Button
Battery charge level
RTC module DS3231SN
Test pads
Qwiic / Stemma QT
SPI ESD protection lines
External NOR flash 64MB

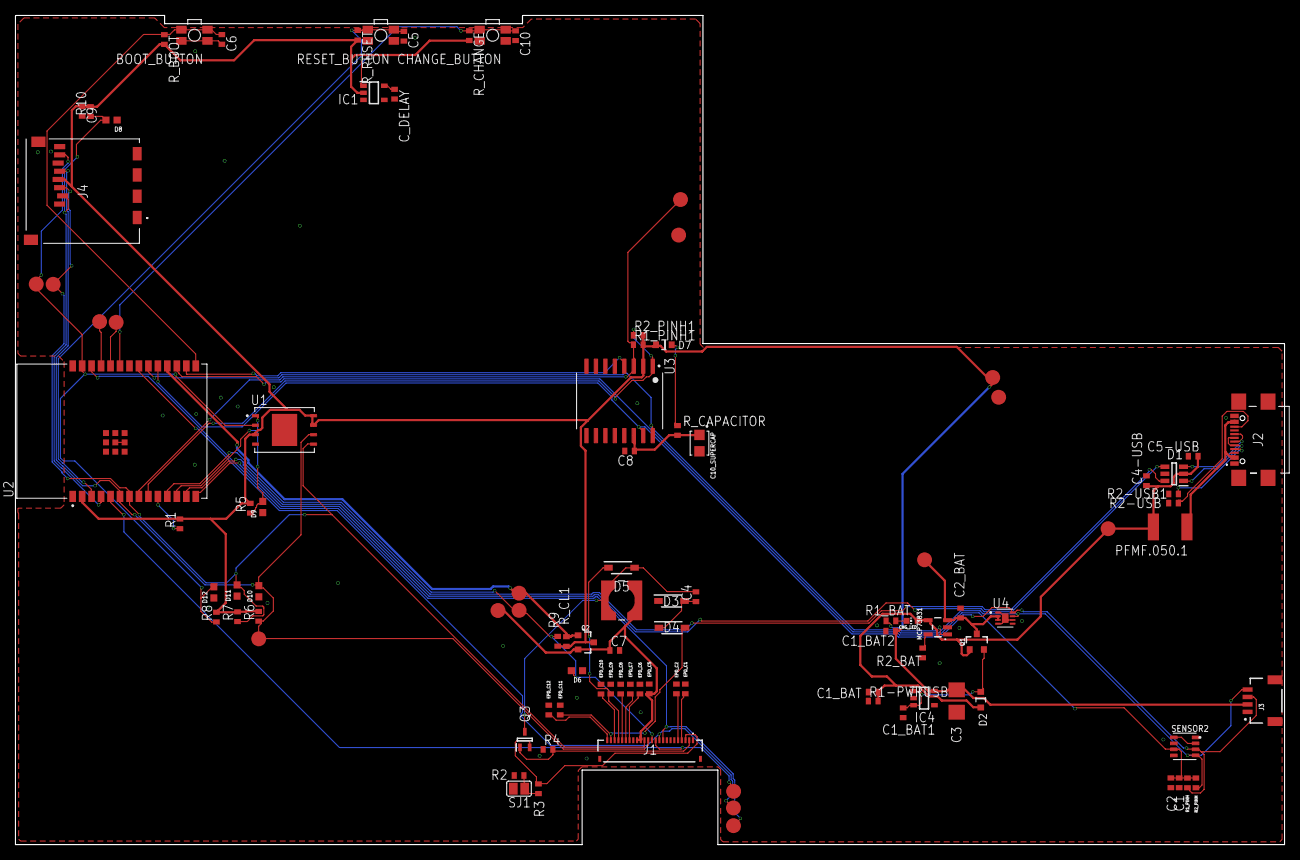
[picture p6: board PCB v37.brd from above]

Board: 2 copper layers, 170.2 x 111.2 mm, 103 parts (0 on the bottom side), 56 nets.

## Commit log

2025-04-06 Upload documents.
    [PCB v28.brd, PCB v28.csv, PnP_PCB v28_front.csv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]
2025-04-06 Update README.md - bom
2025-04-14 Fix issues
    [PCB v28.brd, PCB v28.csv, PCB v37.brd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]

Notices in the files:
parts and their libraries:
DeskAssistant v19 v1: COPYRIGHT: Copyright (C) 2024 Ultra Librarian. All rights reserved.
